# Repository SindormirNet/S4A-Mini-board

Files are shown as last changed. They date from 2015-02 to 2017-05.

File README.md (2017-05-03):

<p align="center">
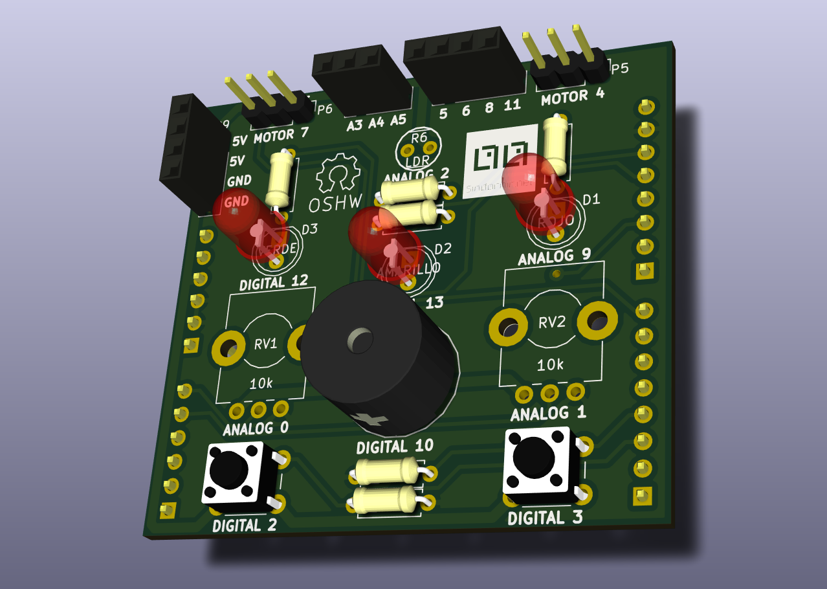
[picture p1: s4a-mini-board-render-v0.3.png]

<div align="center"><i>S4A Mini board render.</i></div>
</p>  

S4A Mini Board
========================================

Esta placa es una shield para su uso con Arduino, con el fin de proporcionar de forma cómoda y rápida acceso a los siguientes sensores y actuadores:

-   Entradas:
    +   Dos potenciómetros.
    +   Dos pulsadores.
    +   Una LDR.
-   Salidas:
    +   Dos servomotores.
    +   Dos LED en modo digital.
    +   Un LED en modo PWM.
    +   Un zumbador.
-   Conexiones:
    +   Cabeceras de conexión para Arduino UNO.
    +   Pines de alimentación (5V y GND).
    +   Pines de E/S de Arduino no utilizados por la shield. Pines A3, A4, A5, 5, 6, 8 y 11 

Es compatible con placas Arduino con capacidad para shield, como las placas UNO, Leonardo o Mega. No requiere la instalación de ninguna librería específica.

<p align="center">
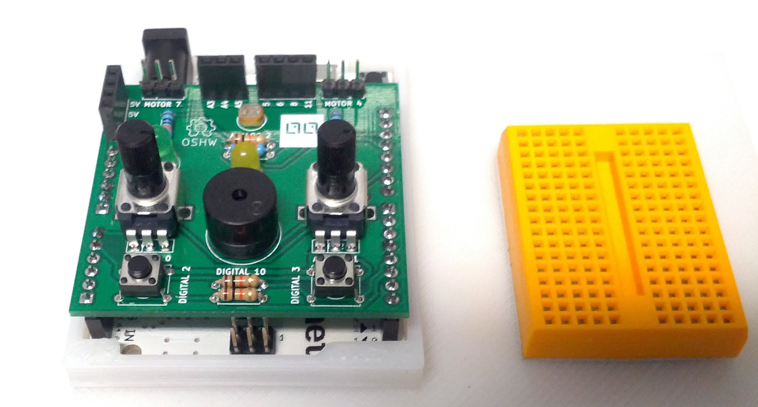
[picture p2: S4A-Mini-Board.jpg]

<div align="center"><i>S4A Mini board real (v0.1).</i></div>
</p>

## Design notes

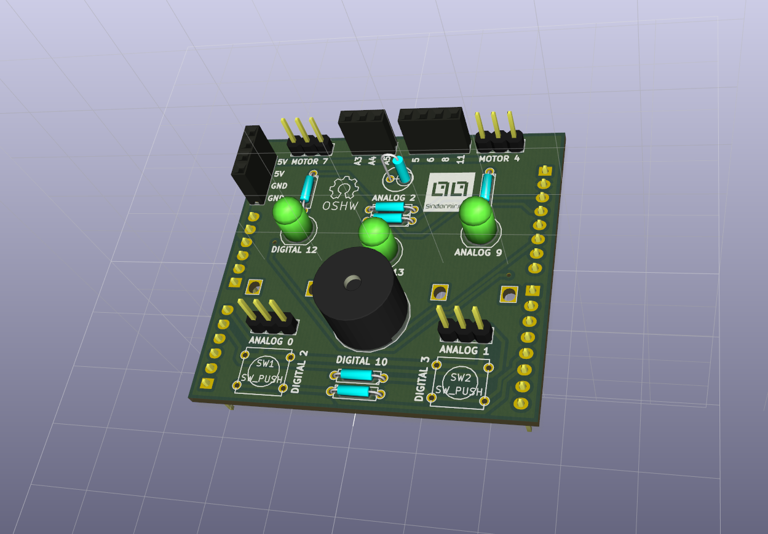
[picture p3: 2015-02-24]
s4a-mini-board-render-v0.1.png

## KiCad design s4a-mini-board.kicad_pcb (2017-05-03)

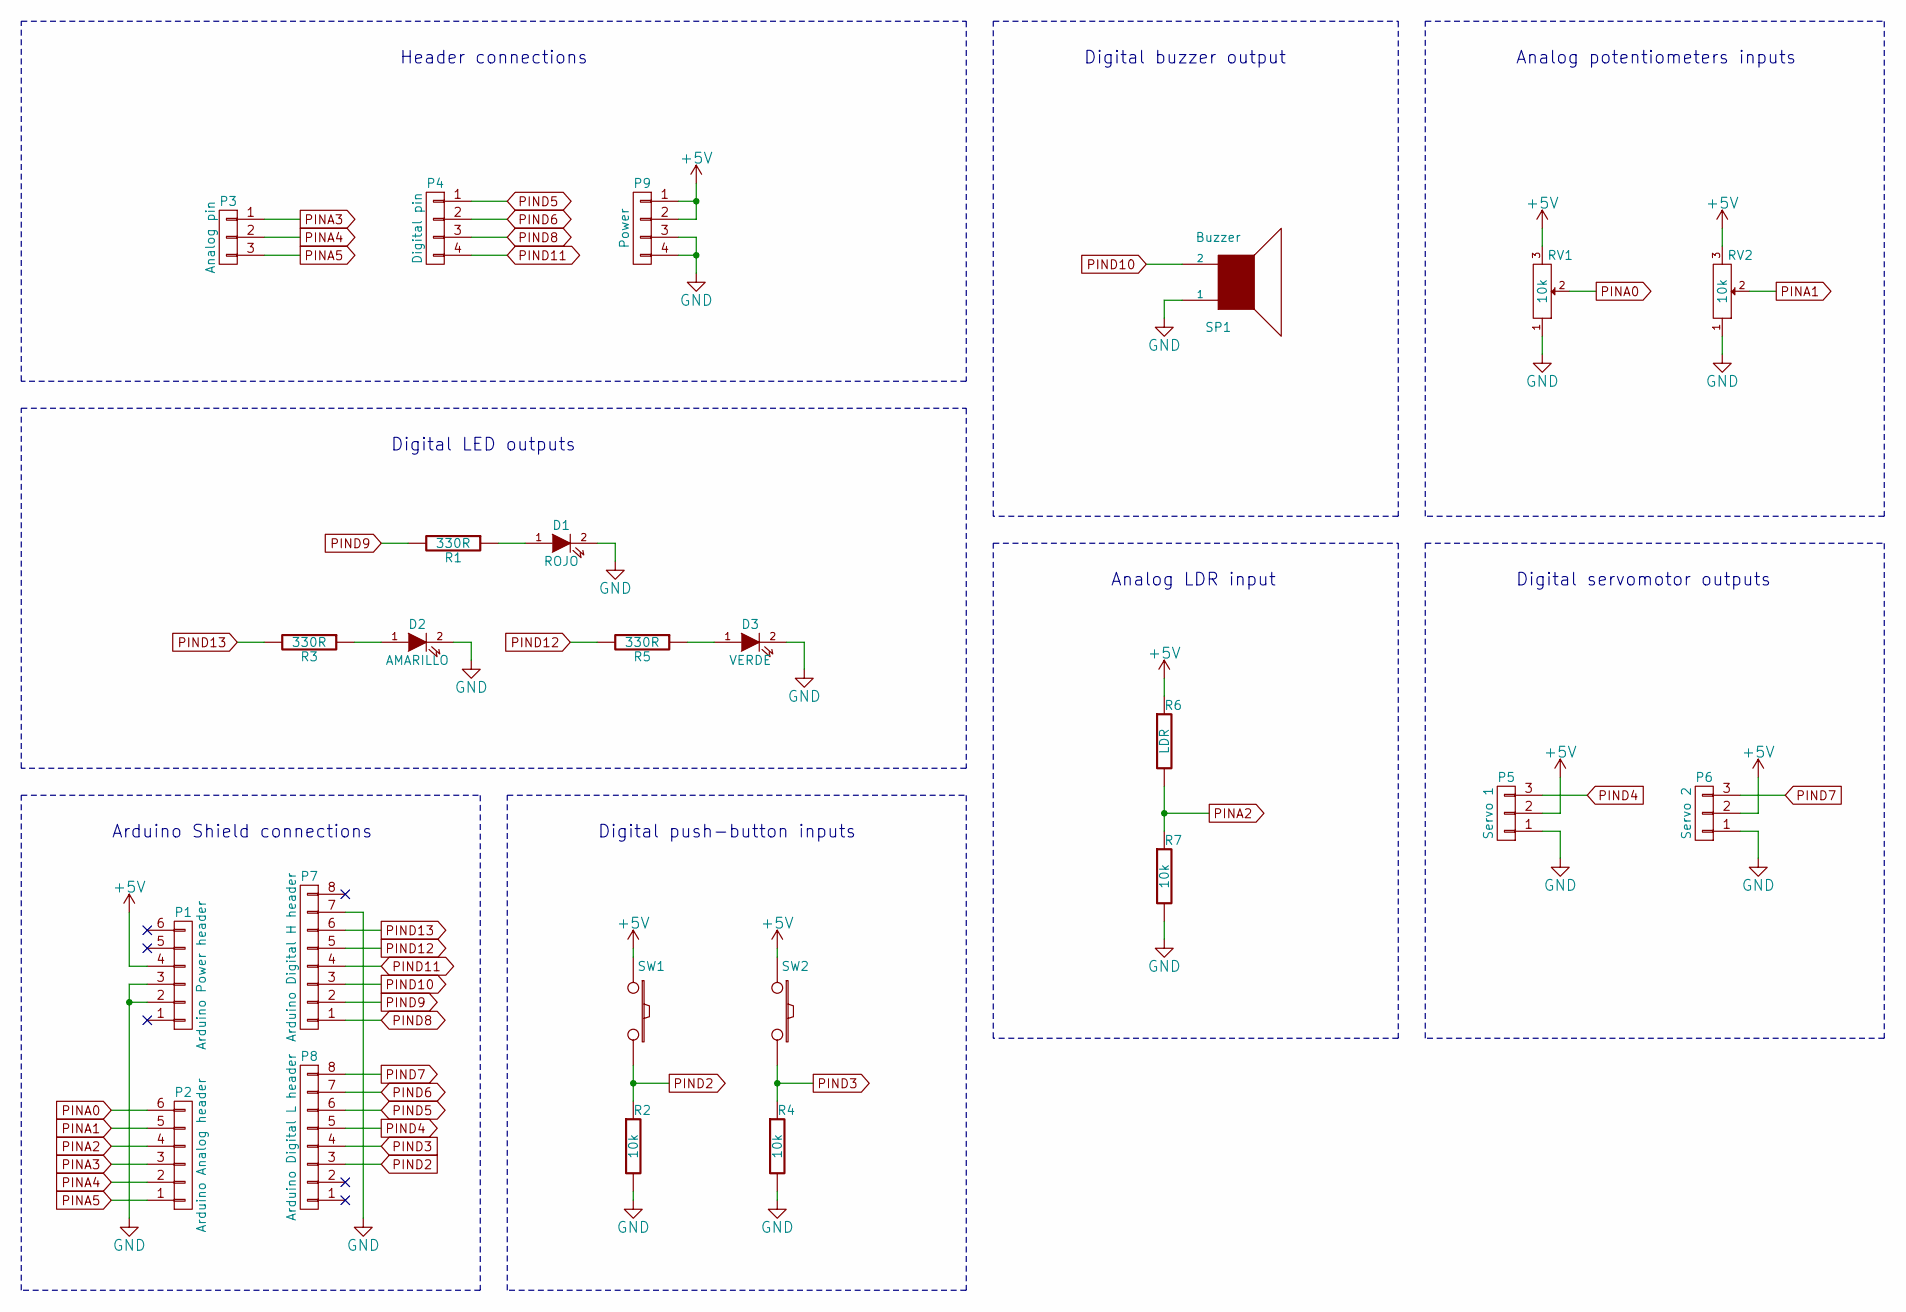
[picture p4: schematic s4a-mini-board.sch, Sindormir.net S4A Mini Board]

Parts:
D1: ROJO; LED_D5.0mm
D2: AMARILLO; LED_D5.0mm
D3: VERDE; LED_D5.0mm
P1: Arduino Power header; Pin_Header_Straight_1x06_Pitch2.54mm
P2: Arduino Analog header; Pin_Header_Straight_1x06_Pitch2.54mm
P3: Analog pin; Socket_Strip_Straight_1x03_Pitch2.54mm
P4: Digital pin; Socket_Strip_Straight_1x04_Pitch2.54mm
P5: Servo 1; Pin_Header_Straight_1x03_Pitch2.54mm
P6: Servo 2; Pin_Header_Straight_1x03_Pitch2.54mm
P7: Arduino Digital H header; Pin_Header_Straight_1x08_Pitch2.54mm
P8: Arduino Digital L header; Pin_Header_Straight_1x08_Pitch2.54mm
P9: Power; Socket_Strip_Straight_1x04_Pitch2.54mm
R1, R3, R5: 330R; R_Axial_DIN0207_L6.3mm_D2.5mm_P7.62mm_Horizontal
R2, R4, R7: 10k; R_Axial_DIN0207_L6.3mm_D2.5mm_P7.62mm_Horizontal
R6: LDR; Resistor_LDR_4.9x4.2_RM2.54
RV1, RV2: 10k; Potentiometer_Alps_RK09K_Horizontal
SP1: Buzzer; MagneticBuzzer_ProSignal_ABI-009-RC
SW1, SW2: PULSA; SW_PUSH_6mm_h5mm

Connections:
+5V: P1.4, P5.2, P6.2, P9.1, P9.2, R6.1, RV1.3, RV2.3, SW1.1, SW2.1
GND: D1.2 (K), D2.2 (K), D3.2 (K), P1.2, P1.3, P5.1, P6.1, P7.7, P9.3, P9.4, R2.2, R4.2, R7.2, RV1.1, RV2.1, SP1.1
unnamed: D1.1 (A), R1.1
unnamed: D2.1 (A), R3.1
unnamed: D3.1 (A), R5.1
PINA0: P2.6, RV1.2
PINA1: P2.5, RV2.2
PINA2: P2.4, R6.2, R7.1
PINA3: P2.3, P3.1
PINA4: P2.2, P3.2
PINA5: P2.1, P3.3
PIND2: P8.3, R2.1, SW1.2
PIND3: P8.4, R4.1, SW2.2
PIND4: P5.3, P8.5
PIND5: P4.1, P8.6
PIND6: P4.2, P8.7
PIND7: P6.3, P8.8
PIND8: P4.3, P7.1
PIND9: P7.2, R1.2
PIND10: P7.3, SP1.2
PIND11: P4.4, P7.4
PIND12: P7.5, R5.2
PIND13: P7.6, R3.2

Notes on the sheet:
Arduino Shield connections
Digital push-button inputs
Analog potentiometers inputs
Digital servomotor outputs
Analog LDR input
Digital buzzer output
Header connections
Digital LED outputs

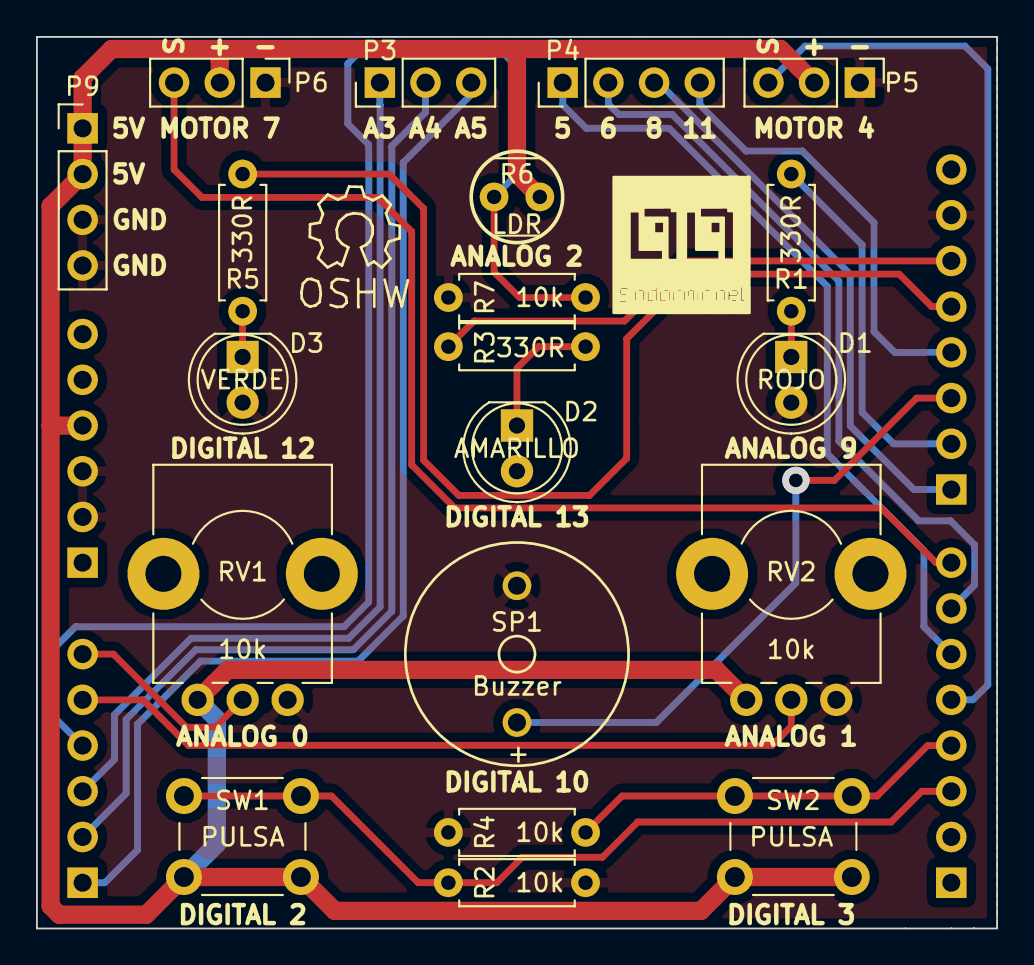
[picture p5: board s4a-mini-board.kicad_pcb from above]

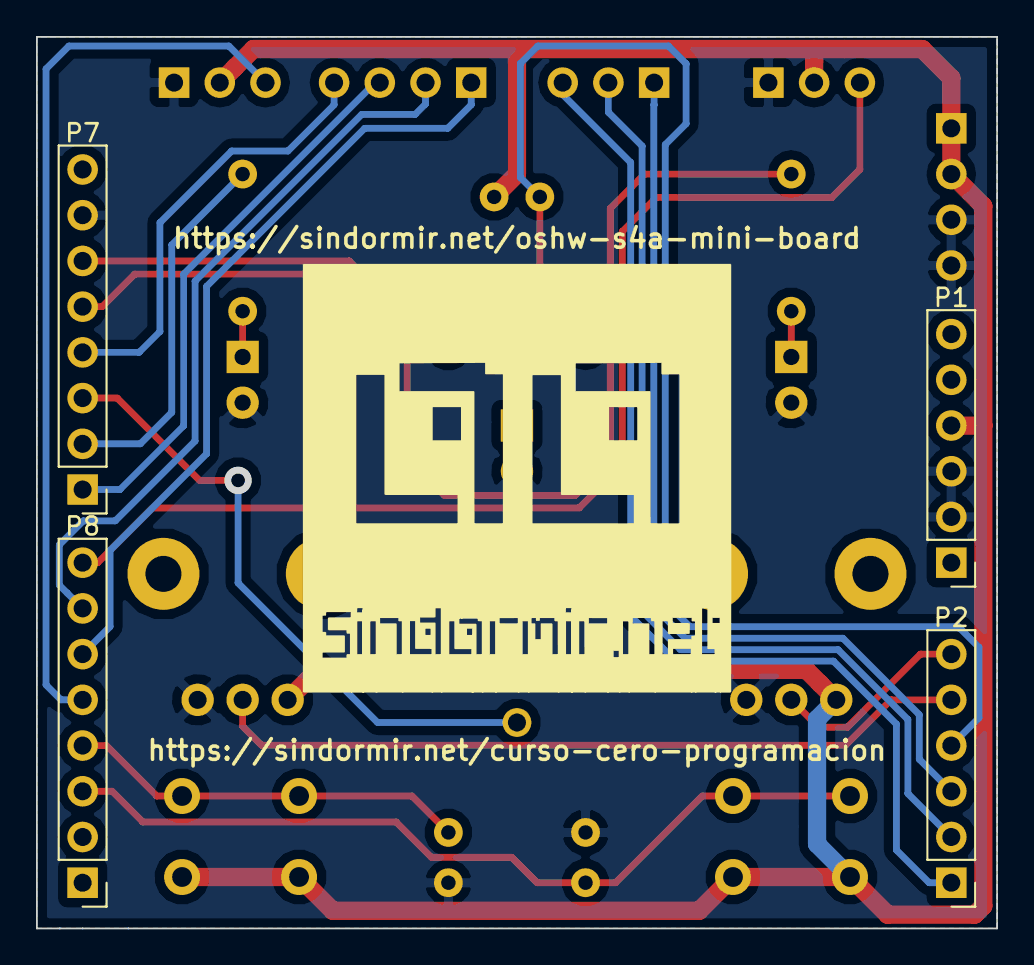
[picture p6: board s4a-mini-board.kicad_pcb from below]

Board: 2 copper layers, 53.3 x 49.5 mm, 25 parts (4 on the bottom side), 23 nets.

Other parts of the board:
Symbol_OSHW-Logo_SilkScreen: VAL**; Symbol_OSHW-Logo_SilkScreen

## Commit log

2015-02-24 Versión inicial. Placa funcional 100%
    [curso_cero.kicad_pcb, curso_cero.sch]
2015-02-25 Añadido README y subida foto de la placa
2017-03-22 Cambios para las nuevas versiones de Kicad. Corregidos fallos estéticos
    [curso_cero.kicad_pcb, curso_cero.sch]
2017-04-28 cambiados footprints por reemplazos de nueva librería kicad
    [curso_cero.sch]
2017-04-28 recolocado esquematico, corregida polaridad de conectores y buzzer
    [curso_cero.sch]
2017-04-28 editado recuadro de esquematico
    [curso_cero.sch]
2017-04-28 eliminadas librerias de esquematico huerfanas
2017-04-29 añadidos valores de LED segun color
    [curso_cero.sch]
2017-04-29 corregido error en polaridad de conector entradas analogicas
    [curso_cero.sch]
2017-04-29 corregido nombre de net pin D10
    [curso_cero.sch]
2017-04-29 cambiado valores pulsadores
    [curso_cero.sch]
2017-04-29 comprobado y recolocada posicion cabeceras Arduino, añadidas cotas en mil, optimizacion de trazado, rellenado recuadro de datos de PCB, editadas clases de nets, reubicados nuevos footprints de boton 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
    [curso_cero.kicad_pcb]
2017-04-29 renombrados archivos segun nombre pcb
    [s4a-mini-board.kicad_pcb, s4a-mini-board.sch]
2017-04-29 modificada ruta de imagen en README

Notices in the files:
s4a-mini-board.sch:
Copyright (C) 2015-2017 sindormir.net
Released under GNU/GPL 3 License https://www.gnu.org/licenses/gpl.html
